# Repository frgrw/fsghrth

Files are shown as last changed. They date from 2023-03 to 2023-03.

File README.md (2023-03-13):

# Design Files for Wired Sculpt Conversion Board

This repository contains the schematic and layout files for the [Microsoft Sculpt Wired Conversion Mod](https://chadaustin.me/2021/02/wired-sculpt/).

To get the board manufactured:
1) Install Kicad & the PCBWay plugin. Use the plugin to start an order, select HASL lead-free if you want lead-free. The other defaults should be fine. Check the box for Assembly service
2) Upload the BOM (bill of materials) and component placement file. These are generated from Kicad: use Tools > "Generate BOM" from the Schematic Editor, and File > "Fabrication Outputs" > "Component placement (.pos)" from the PCB Editor.

## Project Updates

### 2023-02-20

rev6 board with USB-C

Also has some adjustments to board layout, and removes RST switch header to reduce BOM

### 2023-01-06

rev5 board with minor updates.

Rearrange the board layout to fix some Design Rule Check failures and extend the board to match the full layout of the original PCB. A few parts were replaced too, due to supply shortages. No functional changes were made.

### 2021-09-07

The rev4 board design is complete.

When I upgraded the 30-pin ribbon connector to one that fit better, it lowered the resistance to the LEDs. This caused me to burn the microcontroller on a test rev3 board by drawing too much current. So the question became: what values are appropriate for "maximum" brightness on both red and green. Today I found that, given a 5.15V VUSB, whatever resistance in the flex cable, and whatever voltage drop on the LEDs, 150 Ohms gives an even brightness on both red and green. Green draws about 15 mA and red about 10 mA, both within USB low-power spec and the current limits on the microcontroller.

I added an [outputs](outputs/) directory containing the different revisions, and gerber files and drill files generated for either PCBWay or OSH Park.

The biggest challenge right now is the chip shortage. Even some of the capacitors I chose are out of stock. The hardest component to acquire is the ESD protection IC: USBLC6-2SC6. The USBLC6-4SC6 is available, but it would require some tweaking to the PCB layout.

On the software side of things, I added an internal ring buffer for debugging the debouncer. It can be dumped to the HID debug channel by holding both shifts and pressing H. I am trying to figure out why, with my custom low-latency debouncer, sometimes "the" comes out as "theb". For anyone that isn't trying to optimize latency as much as me, you can just run with the default QMK debouncer, which I've never seen produce phantom keys.

### 2021-05-02

One thing that annoyed me about the previous board design was that neither LED was hooked up to a PWM-capable pin and that the green one couldn't be driven, since it wants -5V. I want both lights to work and both to be dimmable.

Rev3 includes a charge pump to produce -5V and two MOSFETs that allow switching the green cathode with PWM.

I also figured out how the Fn switch works: it's a resistor divider that toggles 47K pull-down on a pin with a permanent 1M pull-up. Rev3 includes said 1M pull-up, so the firmware can read the Fn switch's state.

Sadly, it looks like there were many arrangements of media keys on the Sculpt over the years, and most of the media keys have nonsensical icons with behavior that differs on each platform. I'll try to make at least volume and play/pause work.

The parts for board rev 3 arrived last week. Some adjustments were required due to the chip shortage, but it's not too bad. The microcontroller is still available at least.

I attempted assembly of one, and it worked fine, but I screwed up the red and green pins, so I cut some traces and bodged in some kynar wire.

Both lights work!

I have not tested PWM. I did observe that twice as much current is being drawn for each light as I expected. I fear 40 mA could burn out the lights, so I plan to measure an appropriate series resistor this week. It's possible I never had this problem before because I was using a worse-fitting ribbon connector previously. In the past, I always measured 100 Ohms on every pin, but never tested the new ribbon connector.

Also, it kind of sucks that the LED brightness is a function of USB voltage (anywhere between 4.6 V and 5.25 V), but I don't want to include a regulator...

Assembly took about five hours for one board. A lot of that was getting my desk set up. I imagine I could do three boards in ... eight? I think if I used a stencil, hot air assembly could go pretty quickly. Especially if I had a preheater like the MHP30.

A couple people have suggested I set up an Etsy, but if I properly priced in hours of my labor, it would get prohibitive. And I don't want to deal with returns and warranties.

Remaining items before I can say the board is done:
* Order a fourth PCB design with fixed green and red pins
* Include an 0603 resistor on each
* Fix the debouncer
* Add a media key QMK layer, enabled with the Fn switch.

### 2021-04-27

In February, I tried pushing latency further than QMK offers out of the box. I switched from the default debouncer to sym_eager_pk, but since then I've observed some false keydowns and occasionally a phantom keypress. It's common for "the" to produce "theb". (Note that I use the Dvorak key layout.) I haven't looked at the matrix, but it's clear some debouncing is needed on keydown.

I'm planning on writing a custom debouncer that requires at least two frames for a keydown to register and at least 10 ms for a keyup. Having never done AVR optimization, I am trying to get a [simavr](https://github.com/buserror/simavr) benchmark harness up to make sure I don't regress the scan rate.

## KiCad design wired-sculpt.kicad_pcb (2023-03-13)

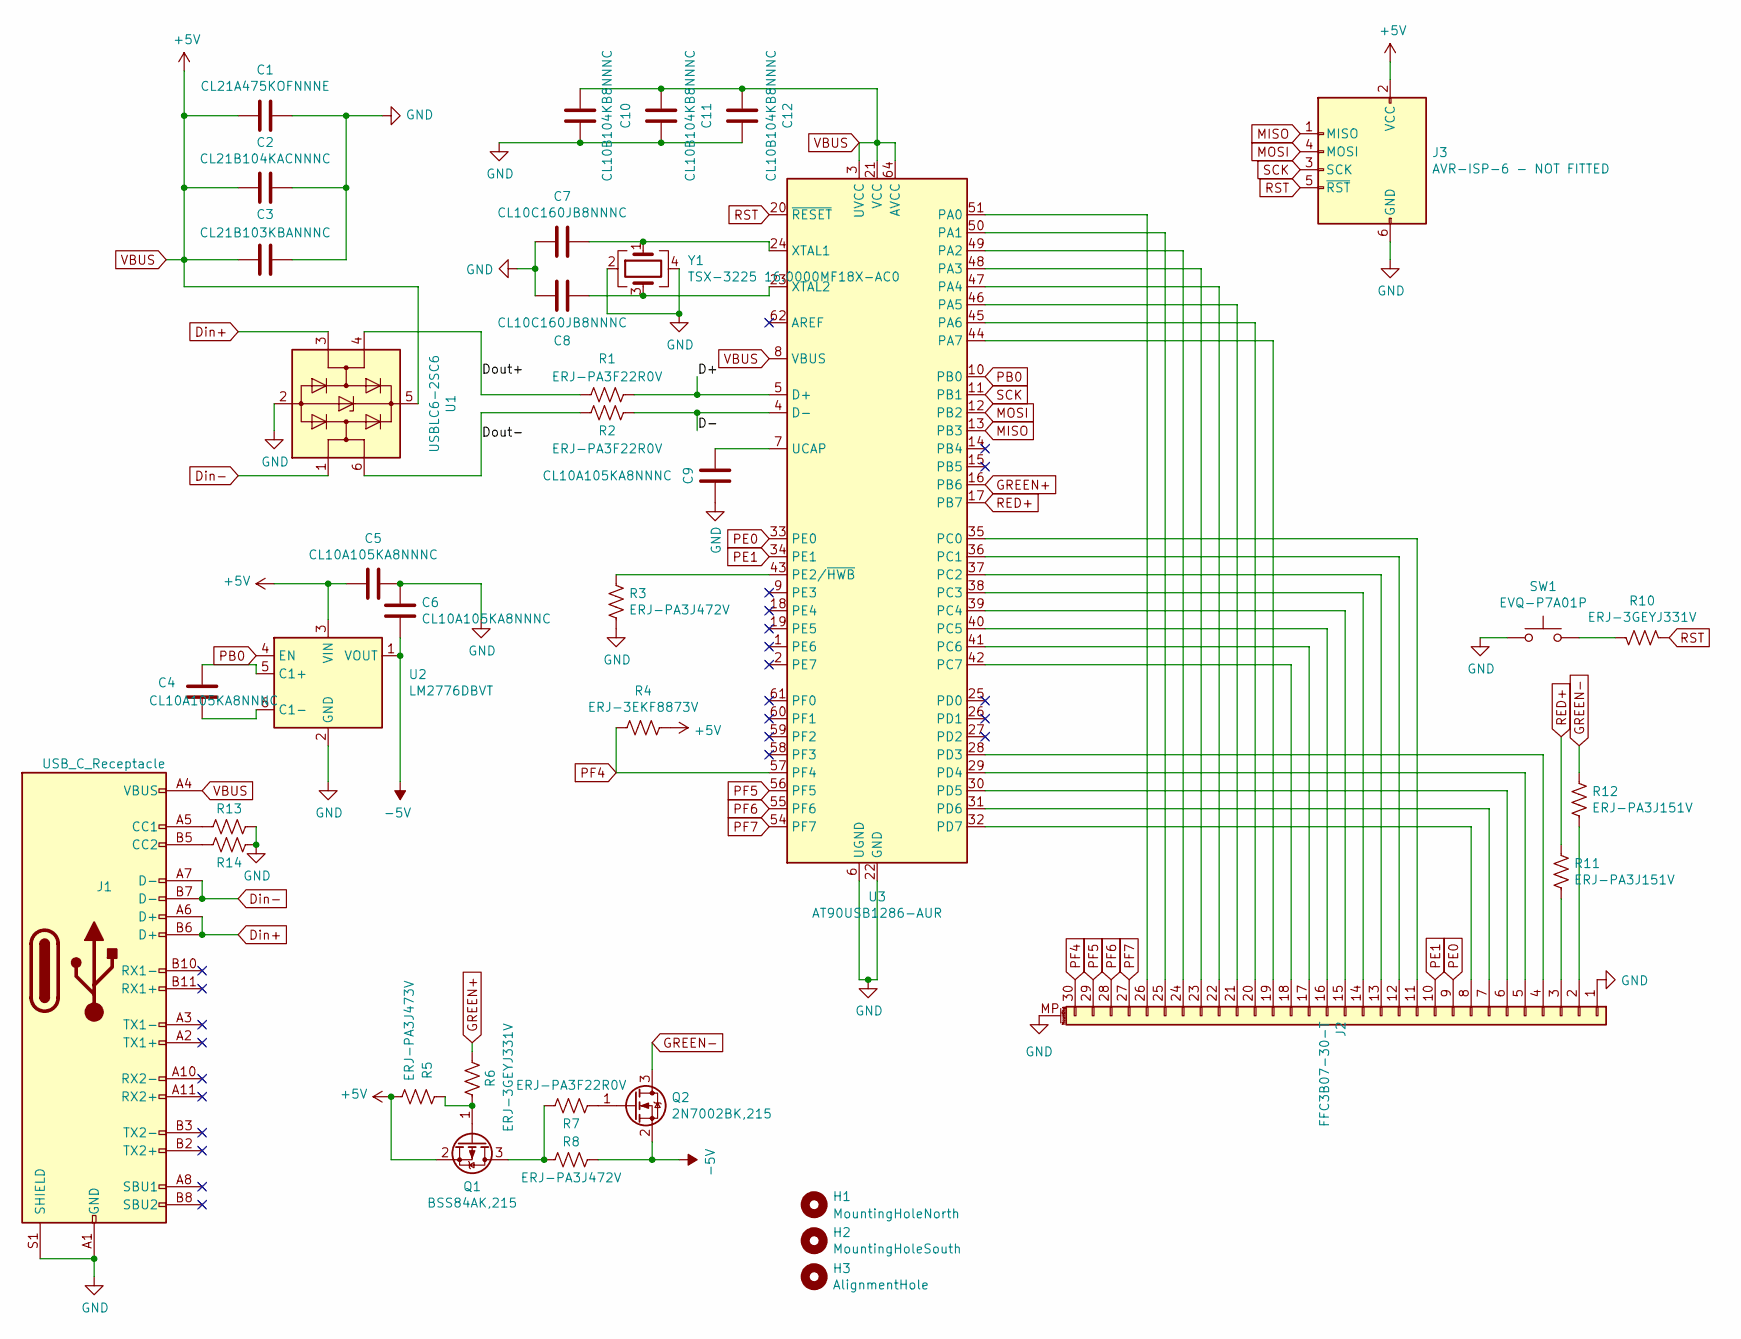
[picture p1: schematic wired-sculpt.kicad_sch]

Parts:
C1: CL21A475KOFNNNE; C_0805_2012Metric; MPN CL21A475KOFNNNE
C2: CL21B104KACNNNC; C_0805_2012Metric; MPN CL21B104KACNNNC
C3: CL21B103KBANNNC; C_0805_2012Metric; MPN CL21B103KBANNNC
C4, C5, C6, C9: CL10A105KA8NNNC; C_0603_1608Metric; MPN CL10A105KA8NNNC
C7, C8: CL10C160JB8NNNC; C_0603_1608Metric; MPN CL10C160JB8NNNC
C10, C11, C12: CL10B104KB8NNNC; C_0603_1608Metric; MPN CL10B104KB8NNNC
H1: MountingHoleNorth; MountingHole_2.2mm_M2
H2: MountingHoleSouth; MountingHole_2.2mm_M2
H3: AlignmentHole; MountingHole_3mm
J1: USB_C_Receptacle; USB_C_Receptacle_Amphenol_12401610E4-2A; MPN 12401610E4#2A
J2: FFC3B07-30-T; TE_3-84952-0_1x30-1MP_P1.0mm_Horizontal; MPN FFC3B07-30-T
J3: AVR-ISP-6 - NOT FITTED; IDC-Header_2x03_P2.54mm_Vertical; MPN AVR-ISP-6 - NOT FITTED
Q1: BSS84AK,215; SOT-23; MPN BSS84AK,215
Q2: 2N7002BK,215; SOT-23; MPN 2N7002BK,215
R1, R2, R7: ERJ-PA3F22R0V; R_0603_1608Metric; MPN ERJ-PA3F22R0V
R3, R8: ERJ-PA3J472V; R_0603_1608Metric; MPN ERJ-PA3J472V
R4: ERJ-3EKF8873V; R_0603_1608Metric; MPN ERJ-3EKF8873V
R5: ERJ-PA3J473V; R_0603_1608Metric; MPN ERJ-PA3J473V
R6, R10: ERJ-3GEYJ331V; R_0603_1608Metric; MPN ERJ-3GEYJ331V
R11, R12: ERJ-PA3J151V; R_0603_1608Metric; MPN ERJ-PA3J151V
R13, R14: ERJ-3EKF5101V; R_0603_1608Metric; MPN ERJ-3EKF5101V
SW1: EVQ-P7A01P; SW_SPST_EVQP7A; MPN EVQ-P7A01P
U1: USBLC6-2SC6; SOT-23-6; MPN USBLC6-2SC6
U2: LM2776DBVT; SOT-23-6; MPN LM2776DBVT
U3: AT90USB1286-AUR; TQFP-64_14x14mm_P0.8mm; MPN AT90USB1286-AUR
Y1: TSX-3225 16.0000MF18X-AC0; Crystal_SMD_3225-4Pin_3.2x2.5mm; MPN TSX-3225 16.0000MF18X-AC0

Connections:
-5V: C6.2, Q2.2 (S), R8.1, U2.1 (VOUT)
/D+: R1.1, U3.5 (D+)
/D-: R2.1, U3.4 (D-)
/Dout+: R1.2, U1.4 (I/O2)
/Dout-: R2.2, U1.6 (I/O1)
Din+: J1.A6 (D+), J1.B6 (D+), U1.3 (I/O2)
Din-: J1.A7 (D-), J1.B7 (D-), U1.1 (I/O1)
GND: C1.1, C2.1, C3.1, C5.1, C6.1, C7.2, C8.2, C9.2, C10.1, C11.1, C12.1, J1.A1 (GND), J1.A12 (GND), J1.B1 (GND), J1.B12 (GND), J1.S1 (SHIELD), J2.1, J2.MP (MountPin), J3.6 (GND), R3.2, R13.1, R14.1, SW1.1, U1.2 (GND), U2.2 (GND), U3.6 (UGND), U3.22 (GND), U3.53 (GND), U3.63 (GND), Y1.2, Y1.4
GREEN+: R6.2, U3.16 (PB6)
GREEN-: Q2.3 (D), R12.1
MISO: J3.1 (MISO), U3.13 (PB3)
MOSI: J3.4 (MOSI), U3.12 (PB2)
unnamed: C4.1, U2.5 (C1+)
unnamed: C4.2, U2.6 (C1-)
unnamed: C7.1, U3.24 (XTAL1), Y1.1
unnamed: C8.1, U3.23 (XTAL2), Y1.3
unnamed: C9.1, U3.7 (UCAP)
unnamed: J1.A5 (CC1), R13.2
unnamed: J1.B5 (CC2), R14.2
unnamed: J2.2, R12.2
unnamed: J2.3, R11.2
unnamed: J2.4, U3.28 (PD3)
unnamed: J2.5, U3.29 (PD4)
unnamed: J2.6, U3.30 (PD5)
unnamed: J2.7, U3.31 (PD6)
unnamed: J2.8, U3.32 (PD7)
unnamed: J2.11, U3.35 (PC0)
unnamed: J2.12, U3.36 (PC1)
unnamed: J2.13, U3.37 (PC2)
unnamed: J2.14, U3.38 (PC3)
unnamed: J2.15, U3.39 (PC4)
unnamed: J2.16, U3.40 (PC5)
unnamed: J2.17, U3.41 (PC6)
unnamed: J2.18, U3.42 (PC7)
unnamed: J2.19, U3.44 (PA7)
unnamed: J2.20, U3.45 (PA6)
unnamed: J2.21, U3.46 (PA5)
unnamed: J2.22, U3.47 (PA4)
unnamed: J2.23, U3.48 (PA3)
unnamed: J2.24, U3.49 (PA2)
unnamed: J2.25, U3.50 (PA1)
unnamed: J2.26, U3.51 (PA0)
unnamed: Q1.1 (G), R5.1, R6.1
unnamed: Q1.3 (D), R7.2, R8.2
unnamed: Q2.1 (G), R7.1
unnamed: R3.1, U3.43 (PE2/~HWB)
unnamed: R10.2, SW1.2
PB0: U2.4 (EN), U3.10 (PB0)
PE0: J2.9, U3.33 (PE0)
PE1: J2.10, U3.34 (PE1)
PF4: J2.30, R4.2, U3.57 (PF4)
PF5: J2.29, U3.56 (PF5)
PF6: J2.28, U3.55 (PF6)
PF7: J2.27, U3.54 (PF7)
RED+: R11.1, U3.17 (PB7)
RST: J3.5 (~RST), R10.1, U3.20 (~RESET)
SCK: J3.3 (SCK), U3.11 (PB1)
VBUS: C1.2, C2.2, C3.2, C5.2, C10.2, C11.2, C12.2, J1.A4 (VBUS), J1.A9 (VBUS), J1.B4 (VBUS), J1.B9 (VBUS), J3.2 (VCC), Q1.2 (S), R4.1, R5.2, U1.5 (VBUS), U2.3 (VIN), U3.3 (UVCC), U3.8 (VBUS), U3.21 (VCC), U3.52 (VCC), U3.64 (AVCC)

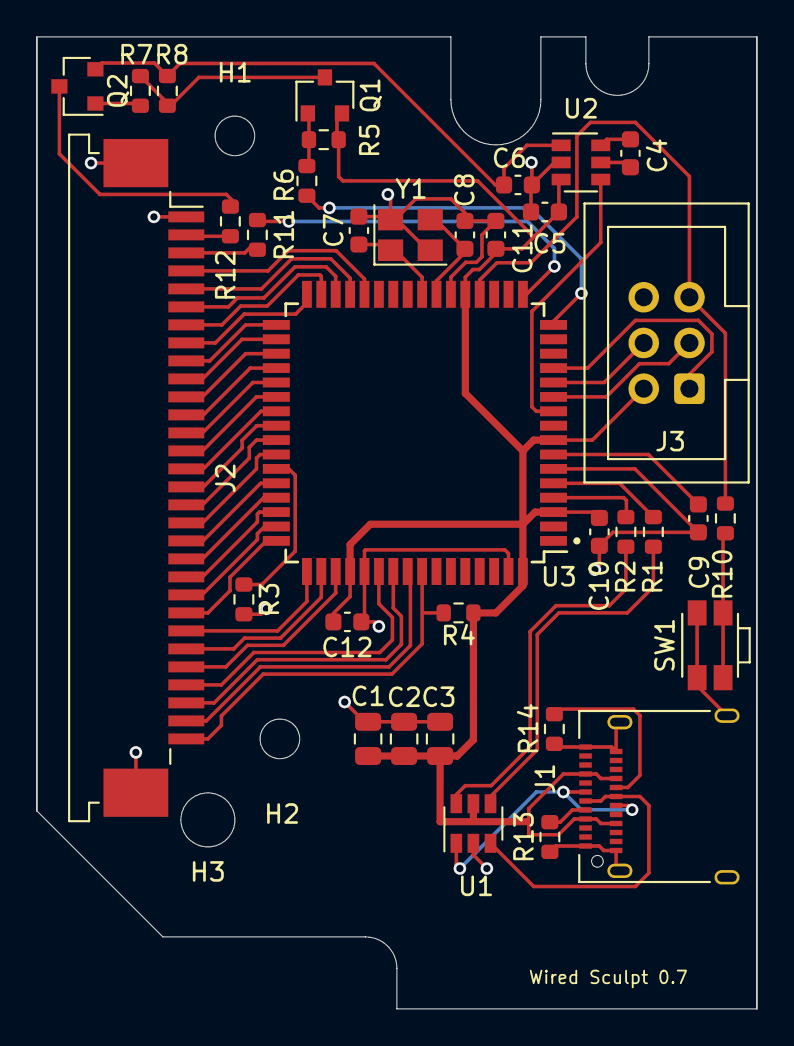
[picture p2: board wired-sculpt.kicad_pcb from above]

Board: 2 copper layers, 40.0 x 54.0 mm, 38 parts (0 on the bottom side), 58 nets.

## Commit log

2022-12-30 Update Kicad files to Kicad 6.0
    [wired-sculpt.kicad_pcb, wired-sculpt.kicad_sch, wired-sculpt.sch]
2022-12-30 Fix linkage of AT90 symbol
    [wired-sculpt.kicad_pcb, wired-sculpt.kicad_sch]
2022-12-30 Extend PCB to fully match original
    [wired-sculpt.kicad_pcb]
2022-12-30 Redo layout to resolve some DRC errors
    [wired-sculpt.kicad_pcb]
2023-01-07 Add MPN to all components
    [wired-sculpt.kicad_pcb, wired-sculpt.kicad_sch]
2023-01-07 Fix interior edge cut radius
    [wired-sculpt.kicad_pcb]
2023-01-07 Copy MPN back to Value field
    This is for compatbility with the JLCPCB plugin
    [wired-sculpt.kicad_pcb, wired-sculpt.kicad_sch]
2023-01-07 Change microcontroller and one FET MPN
    Fixes mismatch that PCBWay flagged
    [wired-sculpt.kicad_pcb, wired-sculpt.kicad_sch]
2023-01-07 Update README with rev5 board
2023-01-07 Properly ground mounting pads for FFC
    [wired-sculpt.kicad_pcb, wired-sculpt.kicad_sch]
2023-01-07 Exclude holes and ISP from BOM
    [wired-sculpt.kicad_pcb, wired-sculpt.kicad_sch]
2023-02-15 Shift header down 1mm
    This fits more closely to the original board
    [wired-sculpt.kicad_pcb]
2023-02-17 Remove reset switch header
    [wired-sculpt.kicad_pcb, wired-sculpt.kicad_sch]
2023-02-20 Change connector to USB-C
    [wired-sculpt.kicad_pcb, wired-sculpt.kicad_sch]
2023-03-06 Change reset switch to horizontal
    [wired-sculpt.kicad_pcb, wired-sculpt.kicad_sch]
2023-03-12 Increase H3 to 3mm
    Slightly more tolerance is needed. Board fit in one of my keyboards, but
    not the other
    [wired-sculpt.kicad_pcb, wired-sculpt.kicad_sch]
2023-03-13 Remove on-board status LED
    [wired-sculpt.kicad_pcb, wired-sculpt.kicad_sch]
2023-03-13 Bump on-board version number
    [wired-sculpt.kicad_pcb]
2023-03-13 Change output file path for .pos file
    [wired-sculpt.kicad_pcb]
